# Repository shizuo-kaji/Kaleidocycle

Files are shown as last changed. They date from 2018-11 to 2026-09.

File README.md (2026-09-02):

[English](README.md) | [日本語](README.ja.md)

# Kaleidocycle: Geometry of Closed Linkages

Kaleidocycles are closed linkage mechanisms shaped like discrete Möbius bands.
Each unit consists of tetrahedral links that flip inside-out by rotating around
hinged joints, producing everting motions reminiscent of bubble rings. This
repository gathers asset needed to model, simulate, and fabricate these
mechanisms: Python tooling, Maple/Mathematica notebooks,
paper templates, and 3D-printable parts.

## Interactive demo

**[Open Kaleidocycle Studio](https://shizuo-kaji.github.io/Kaleidocycle/)**

The studio runs the animation by mKdV hierarchy and semi-discrete sine–Gordon flows,
and supports interactive editing of vertex positions and torsion-angles.

## Repository Tour
- [`python/`](python/) — Python scripts (package sources under
  `src/kaleidocycle/`, notebooks, examples)
- [`Kaleidocycle.mw`](Kaleidocycle.mw) / [`Kaleidocycle.nb`](Kaleidocycle.nb) —
  Maple and Mathematica scripts for symbolic construction, visualization, and
  template export
- [`3d_model/`](3d_model/) — STL for 3D printing
  (models by [Kamagata Design Studio](https://kdstudio.jp/))
- [`paper_model/`](paper_model/) — printable templates for hand-folded models
- [`hexagon/`](hexagon/) — hexaflexagon cousin plus a pictorial folding guide
  for kaleidocycles
- [`LICENSE`](LICENSE) — MIT license for the code (see the patent note below)

## Quick Start
### Python toolkit
1. `cd python`
2. `uv venv .venv && source .venv/bin/activate`
3. `pip install -e .[dev]`
4. `pytest` (or `pytest -k geometry`) to run the suite
5. `jupyter lab notebooks/FindKaleidocycles.ipynb` for interactive exploration

### Maple / Mathematica
Open `Kaleidocycle.mw` (Maple) or `Kaleidocycle.nb` (Mathematica) to reproduce
symbolic computations. Both scripts include visualization helpers
and export functions for paper templates and motion studies.

### Physical model assets
- Print STL files from `3d_model/` to fabricate kaleidocycles
- Use `paper_model/` templates for hand-folded prototypes; the `hexagon/` folder
  also contains instructions

## References & Further Reading
### Technical publications
- Shizuo Kaji, Kenji Kajiwara, Shota Shigetomi,
  [*An explicit construction of Kaleidocycles by elliptic theta functions*](https://doi.org/10.1111/sapm.70224),
  Studies in Applied Mathematics, 156, no. 5 (2026): e70224, [arXiv:2308.04977](https://arxiv.org/abs/2308.04977)
- Shizuo Kaji, Kenji Kajiwara, Hyeongki Park,
  [*Linkage Mechanisms Governed by Integrable Deformations of Discrete Space Curves*](https://arxiv.org/abs/1903.06360),
  in *Nonlinear Systems and Their Remarkable Mathematical Structures*, Vol. 2,
  CRC Press, 2019
- Shizuo Kaji,
  [*A closed linkage mechanism having the shape of a discrete Möbius strip*](https://arxiv.org/abs/1909.02885),
  JSPE Spring Meeting Symposium, 17 Mar 2018

<!-- ### Talks, slides, and abstracts
- (slides) [*Geometry of Kaleidocycles*](https://www.math.kyoto-u.ac.jp/~kaji/papers/Kaleidocycle21.pdf),
  Kyushu-Illinois Strategic Partnership Colloquia Series #2, 11 Mar 2021
- (slides, Japanese) [*Kaleidocycle*](https://www.math.kyoto-u.ac.jp/~kaji/papers/ShapeDesign.pdf),
  13 Mar 2021
- Shizuo Kaji, Eliot Fried, Michael Grunwald, Johannes Schoenke,
  [*Geometry of closed kinematic chain*](https://www.math.kyoto-u.ac.jp/~kaji/files/Kaleidocycle17.pdf),
  IMI Workshop on Mathematics in Interface, Dislocation and Structure of
  Crystals, 29 Aug 2017 -->

### Japanese-language articles
- プレスリリース:
  [現代数学と折紙から生まれた新しい機構「メビウス・カライドサイクル」](https://www.kyushu-u.ac.jp/ja/researches/view/908)
- プレスリリース:
  [任意個数の四面体に対してカライドサイクルの存在を数学的に証明](https://www.kyoto-u.ac.jp/ja/research-news/2026-05-19-3)
- 鍛冶静雄, [動く折り紙「カライドサイクル」をめぐる機構学と幾何学の出会い](https://www.math.kyoto-u.ac.jp/alumni/bulletin9/kaji.pdf), 京都大学数学教室同窓会誌, Vol 9, 2025
- 鍛冶静雄,
  [ユークリッド空間への図形の配置と設計への応用](https://drive.google.com/file/d/1T9TYKBqkQ1LdtojkK5dp09Pkyl5XI_wF/view?usp=sharing)
- 鍛冶静雄,
  [曲線の幾何学から生まれた閉リンク機構](https://drive.google.com/file/d/1CtwQHpcM_HEn3ooKfJ5y40s_B99IqRwR/view?usp=sharing),
  2018年度精密工学会春季大会 シンポジウム資料集, pp. 62–65
- 鍛冶静雄,
  [数理のクロスロード／かたちと動きの数理基盤／(1) リンク万華鏡](https://drive.google.com/file/d/1OzZajghUbhxeA3HFf4-TjSBeRZROcfiD/view?usp=sharing),
  数学セミナー 2019年6月号, 日本評論社
- 鍛冶静雄,
  [かたちを算する／おもちゃのかたち](https://www.nippyo.co.jp/shop/magazine/8418.html),
  数学セミナー 2021年1月号, 日本評論社

## Patent
The specific shape of the Möbius kaleidocycle is covered by the patent
* Shizuo Kaji, Johannes Schoenke, Eliot Fried, Michael Grunwald,
  [*Moebius Kaleidocycle*](https://patentscope2.wipo.int/search/en/detail.jsf?docId=WO2019167941),
  JP2018-033395 (Japan), 2019JP007314 (PCT), WO 2019167941, filed 27 Feb 2018.

However, feel free to use the material here for personal and educational projects.
For commercial use, contact the [Japan Science and Technology Agency](https://www.jst.go.jp/chizai/en/).

Some of the results described above are also published in
- Johannes Schoenke and Eliot Fried,
  [*Single degree of freedom everting ring linkages with nonorientable topology*](https://www.pnas.org/content/116/1/90.abstract),
  *PNAS* 116 (1), 90–95, 2019

## Gallery

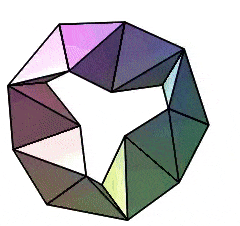
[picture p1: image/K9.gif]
K9

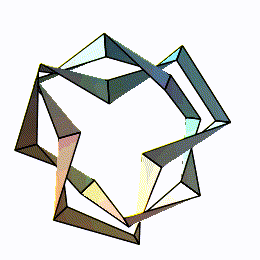
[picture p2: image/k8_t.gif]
K8

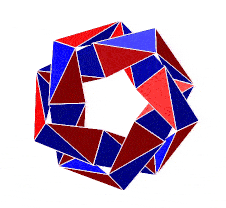
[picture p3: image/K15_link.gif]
K15

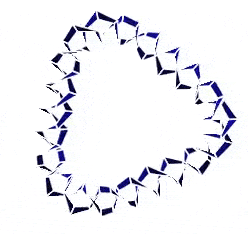
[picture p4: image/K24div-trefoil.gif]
K24div

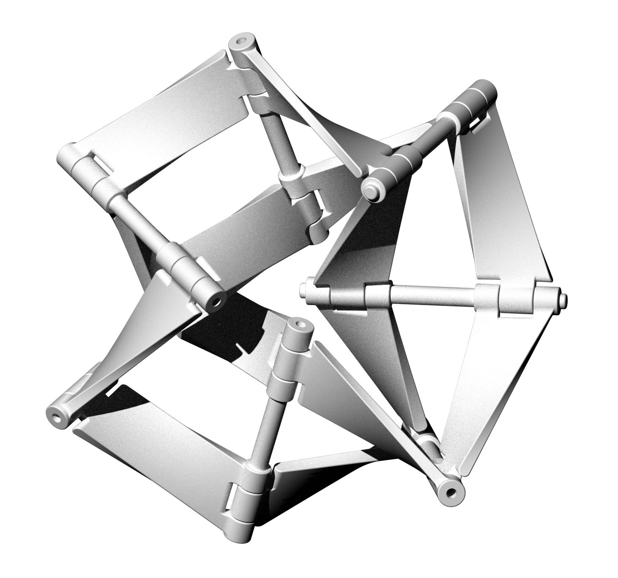
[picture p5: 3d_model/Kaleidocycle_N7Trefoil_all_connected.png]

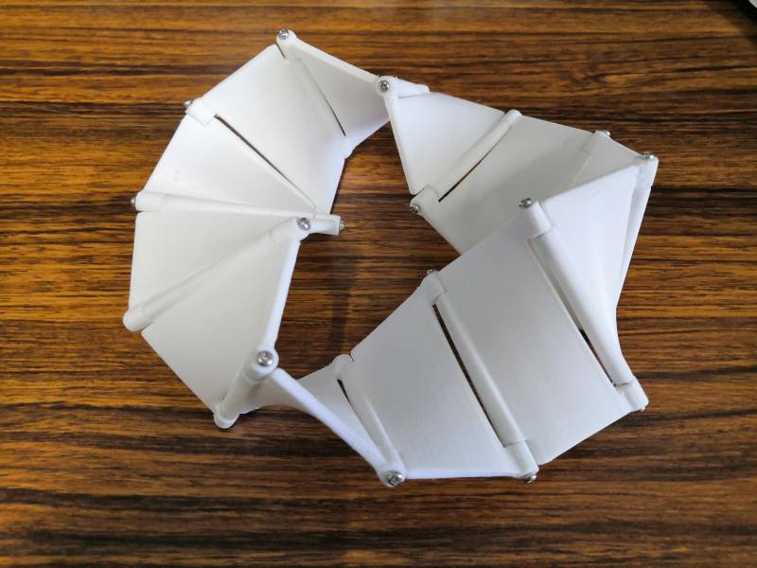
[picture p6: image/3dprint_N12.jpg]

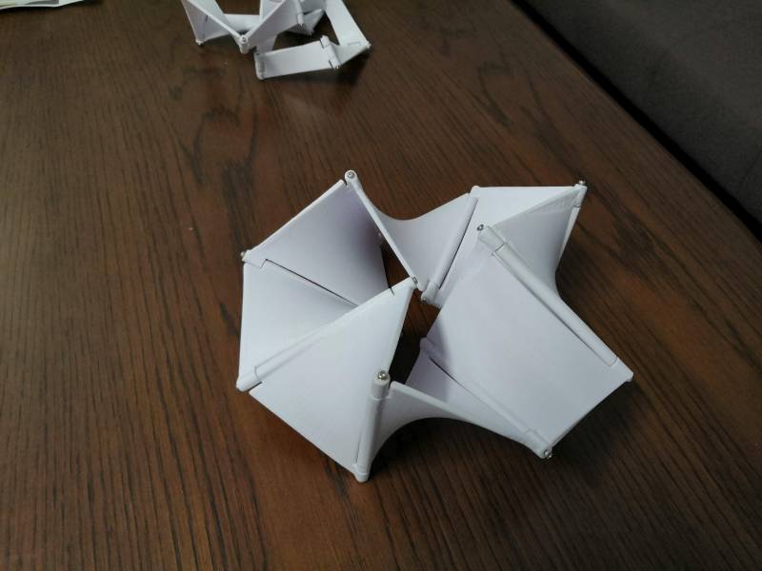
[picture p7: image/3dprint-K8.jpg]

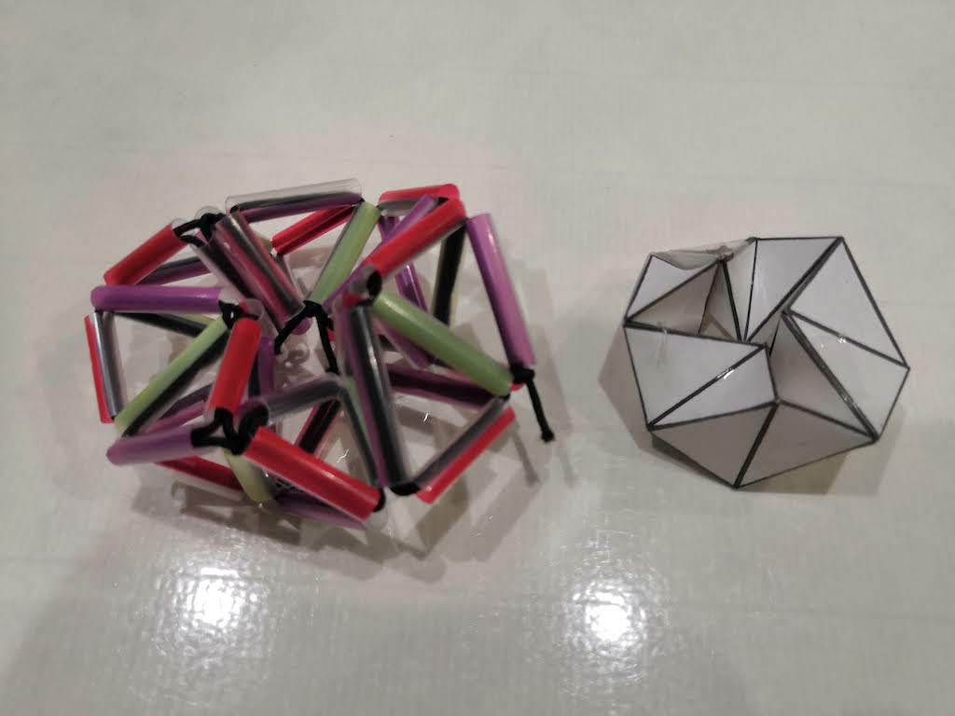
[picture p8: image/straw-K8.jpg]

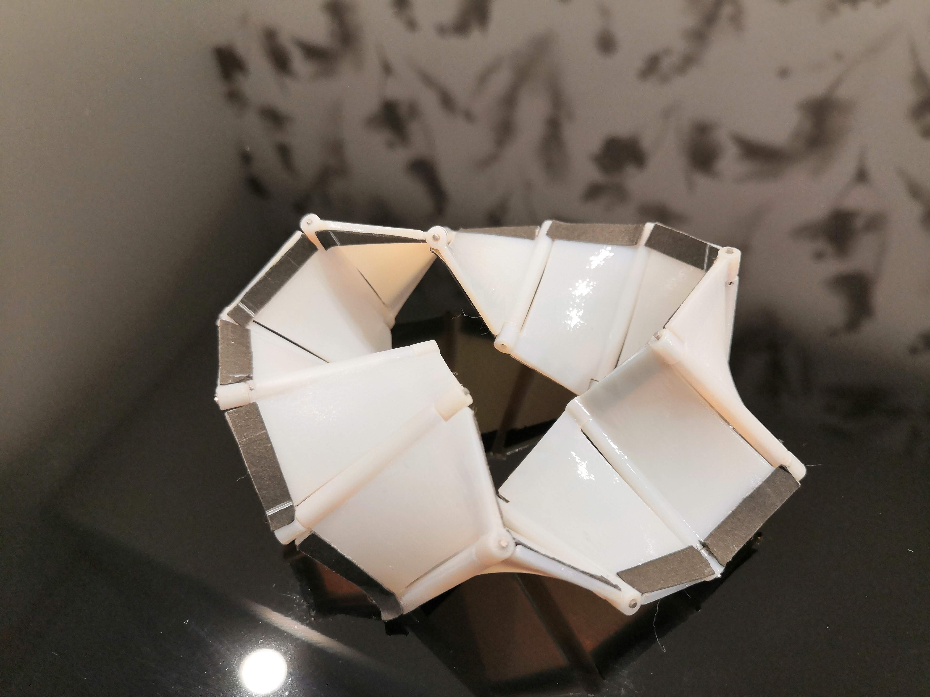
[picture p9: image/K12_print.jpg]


## License
All code and assets in this repository are released under the MIT License (see
[`LICENSE`](LICENSE)). Cite the references above when using or extending the
material in academic work.

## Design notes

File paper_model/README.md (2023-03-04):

[English](README.md) | [日本語](README.ja.md) 

# Paper model of Kaleidocycle

## Paper Plan

- [K7](paper-K7.pdf): Mobius Kaleidocycle with 7 tetrahedra
- [K8](paper-K8.pdf): Mobius Kaleidocycle with 8 tetrahedra
- [K9](paper-K9.pdf): Mobius Kaleidocycle with 9 tetrahedra
- Paper plans for Kaleidocycles with 10 or more tetrahedra can be obtained by [Maple code](../Kaleidocycle.mw)

## How to make

1. Cut along the outer boundary
2. The triangles in the right-most column and the bottom row are the glue allowance
3. Each row makes a tetrahedron
4. Crease every line firmly before folding tetrahedra
5. Horizontal lines should be creased in both mountain and valley and others in mountain
6. Apply some glue on the face of the gluing triangles
7. Fold tetrahedra from the top row
8. Insert the two gluing triangles at the bottom row into the tetrahedron corresponding to the first row

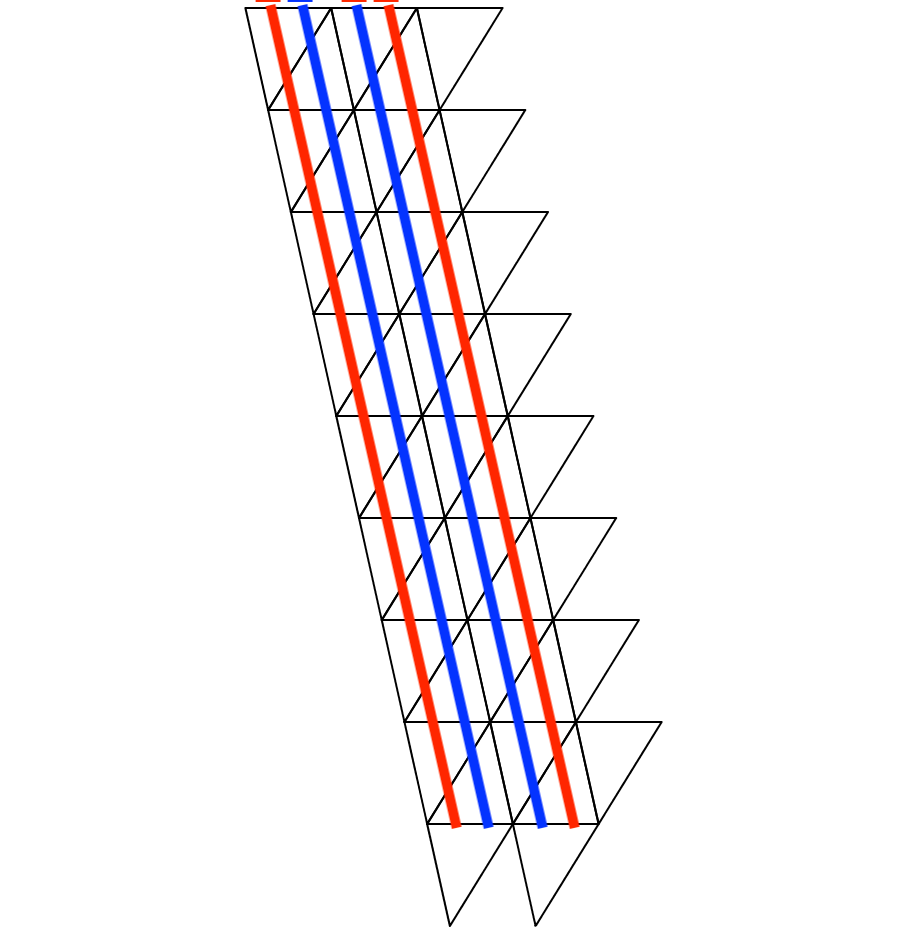
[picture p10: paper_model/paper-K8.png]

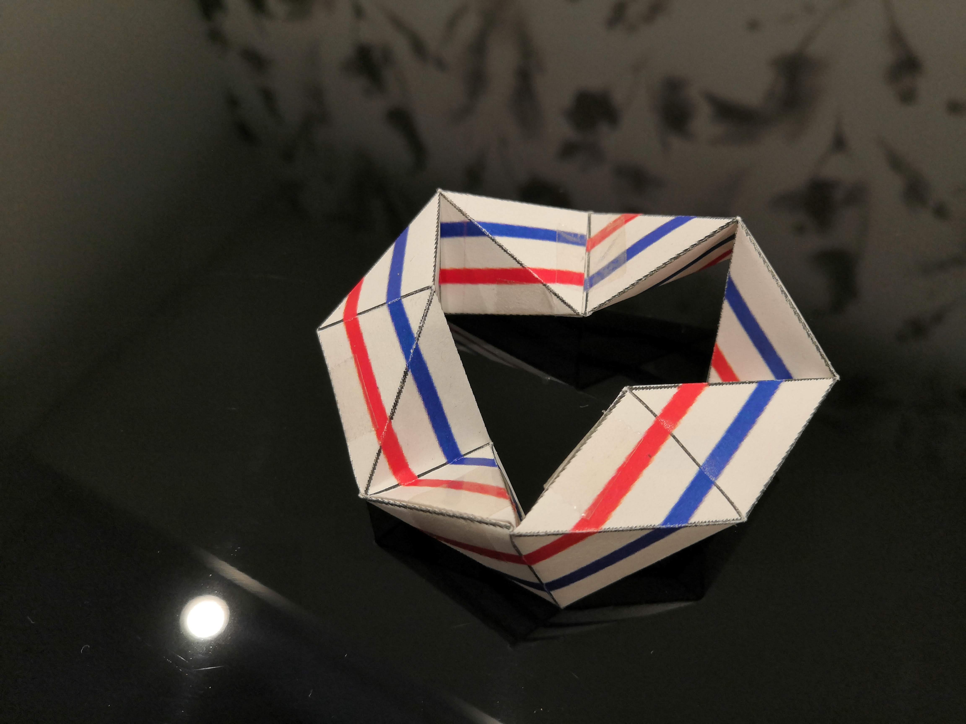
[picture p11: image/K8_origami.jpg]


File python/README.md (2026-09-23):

# Kaleidocycle Python Toolkit

This repository ports the Maple, Mathematica, and MATLAB kaleidocycle code into
a Python package. The package works with an N-kaleidocycle as `N + 1`
unit hinge vectors, also called binormals, in `R^3`. Adjacent hinges have
constant torsion, meaning their pairwise inner products are constant. Oriented
cycles end with the same hinge direction they started with; non-oriented cycles
end with the opposite direction.

The current Python package includes geometry, integrable curvature flows,
energies, constraints, solvers, theta-function constructions, animation tools,
reports, I/O, and plotting.

## Install

```bash
python -m pip install -e ".[dev]"
```

JAX is included in the development dependencies. For a smaller runtime install
with automatic differentiation support, use `python -m pip install -e ".[jax]"`.

Run the test suite with:

```bash
pytest
```

## Notebooks

Interactive examples live in `notebooks/`. Use `%matplotlib widget` for 3D
interaction and make sure the notebook kernel points at the project environment.

- `FindKaleidocycles.ipynb` explores optimization-based construction.
- `ExplicitConstructionWithTheta.ipynb` demonstrates analytic theta-function
  solutions.
- `Animation.ipynb` explores animation utilities.
- `IntegrableDeformations.ipynb` demonstrates the positive mKdV hierarchy,
  its spectral Hamiltonians and lifts, the anti-periodic sine--Gordon flow,
  and numerical conservation.
- `SelfCrossing.ipynb` certifies a K12 self-crossing under the first mKdV flow,
  with static diagnostics and an interactive 3D time slider.
- `KaleidocycleProperties.ipynb` inspects structural properties and residuals.
- `AnimationScalarProperties.ipynb` computes and plots animation diagnostics.
- `BackendComparison.ipynb` compares NumPy and optional JAX solver backends.
- `LocalDoF.ipynb` analyzes infinitesimal and finite degrees of freedom of the
  constraint-preserving motion at a given configuration.

## Interactive web studio

Select **Self-crossing K12 · first mKdV flow** in the studio's built-in menu
for the pre-contact counterexample (`counterexample_k12_self_crossing`). Its
certified decimal inputs are in `data/counterexamples/`, with the certificate
and interactive diagnostics in `notebooks/SelfCrossing.ipynb`. Rebuild the
shared sample and offline fallback with `python scripts/build_self_crossing.py`.

`web/` contains a three.js studio for the integrable hierarchy and constrained
editing of closed constant-torsion kaleidocycles. When it is served over HTTP,
the built-in menu reads the same canonical JSON files in
`data/kaleidocycles/` that notebooks load through `load_sample()`.

**[Open Kaleidocycle Studio](https://shizuo-kaji.github.io/Kaleidocycle/)**

```bash
python -m http.server 8000   # from this directory
```

then open <http://localhost:8000/web/>. Directly opening `web/index.html` also
works, using a generated static fallback because browsers do not permit a
`file://` page to fetch neighbouring JSON files. See `web/README.md` for details.

### Shared notebook/web samples

```python
from kaleidocycle import export_sample, load_sample

cycle = load_sample("generic_k15_noncritical")

# Promote a notebook result to the canonical built-in catalogue.
export_sample(
    cycle,
    "my_named_sample",
    metadata={"kind": "generic", "non_critical": True},
)
```

`export_json()` now writes a top-level `name` too; an explicit `name=...` wins,
then `Kaleidocycle.name`, and finally the output filename is used. After adding
or changing canonical samples, run `python scripts/build_web_samples.py` to
refresh `catalog.json` and the generated fallback used only in direct-file mode.

## Package Layout

- `src/kaleidocycle/geometry.py`: hinge frames, curves, curvature, torsion,
  writhe, twist, linking number, transformations between curves, tangents, and
  binormals, plus the `Kaleidocycle` class.
- `src/kaleidocycle/animation.py`: sine-Gordon flow, step/random animation
  generation, frame cleaning, alignment, sorting, curve conversion, and
  `KaleidocycleAnimation`.
- `src/kaleidocycle/integrable.py`: twisted curvature coordinates, discrete
  Frenet reconstruction, the positive mKdV hierarchy and compatible lifts,
  twisted-Floquet Hamiltonians, the anti-periodic sine--Gordon field, Poisson
  operator, variational recurrence, QRT invariant, and time integration.
- `src/kaleidocycle/theta.py`: Jacobi theta functions, closure equations,
  analytic curves, theta binormals, and theta animations.
- `src/kaleidocycle/constraints.py`: unit norm, closure, alignment, constant
  torsion, anchor, and curvature-recursion residuals.
- `src/kaleidocycle/energies.py`: bending, torsion, and dipole energies.
- `src/kaleidocycle/solvers.py`: optimization dispatch, Newton iteration,
  pseudoinverse utilities, multi-seed search, and curvature/torsion solvers.
- `src/kaleidocycle/optimality.py`: gradients, constraint Jacobians, tangent
  projection, and stationarity checks.
- `src/kaleidocycle/rigidity.py`: rigidity-matrix diagnostics, mechanism and
  self-stress bases, Calladine/Pellegrino counts, Connelly second-order stress
  tests, and finite-motion tracing wrappers.
- `src/kaleidocycle/visualization.py`: centreline, hinge, band, tetrahedron,
  paper-model, energy, and vertex-value plotting.
- `src/kaleidocycle/io.py`: JSON and CSV import/export.
- `src/kaleidocycle/samples.py`: shared named-sample catalogue, promotion, and
  presentable generic-sample selection.
- `src/kaleidocycle/report.py`: formatted diagnostic reports.

## Core Properties

`Kaleidocycle` and `KaleidocycleAnimation` expose the same high-level checks:

| Property | Meaning |
| --- | --- |
| `n` | Number of tetrahedra, equal to `len(hinges) - 1`. |
| `oriented` | Whether the first and last hinge directions agree. |
| `is_closed` | Whether the tangent closure residual is below tolerance. |
| `is_aligned` | Whether endpoint hinges satisfy the alignment rule. |
| `is_unit_norm` | Whether all hinge vectors have unit norm. |
| `constant_torsion` | Common torsion value, or `None` if not constant. |

The corresponding lower-level residuals are available from
`kaleidocycle.constraints`: `closure_residual`, `alignment_residuals`,
`unit_norm_residuals`, `constant_torsion_residuals`, `constraint_residuals`, and
`constraint_penalty`.

## Animation Diagnostics

`KaleidocycleAnimation.compute_scalar_property()` supports built-in scalar
properties:

| Name | Description |
| --- | --- |
| `bending_energy` or `bending` | Bobenko-Suris bending energy of the tangent vectors. |
| `mean_torsion` | Mean torsion angle across hinges. |
| `mean_curvature` | Mean discrete curvature across hinges. |
| `penalty` | Sum of squared constraint residuals. |
| `linking_number` | Topological linking number. |

Custom scalar properties can be added with a function:

```python
def max_curvature(hinges):
    from kaleidocycle.geometry import binormals_to_tangents, pairwise_curvature

    tangents = binormals_to_tangents(hinges, normalize=True)
    curvature = pairwise_curvature(hinges, tangents)
    return float(abs(curvature).max())

anim.compute_scalar_property("max_curvature", func=max_curvature)
```

## Analytic Theta Construction

`generate_theta_curve()` and `generate_theta_binormals()` implement the explicit
theta-function construction from `Kaleidocycle.m`. The binormal path follows the
Mathematica `Bx`, `By`, and `Bz` formulas. For parameters where the reference
formula has a removable near-singularity around `G = 0`, the implementation
automatically re-evaluates the same formula with higher precision instead of
falling back to curve-derived signs.

```python
from kaleidocycle import generate_theta_binormals

v = 0.07227972073349694
r = 0.30353311936556515
y = 0.9155431292909612
binormals = generate_theta_binormals(v, 0.0, r, y, N=38, t=0.0)
```

## Reports And Stationarity

Use `kc.report()` for a compact summary of geometric, topological, energetic,
and constraint diagnostics. Use `kc.is_stationary(energy, config=...)` to
project an energy gradient onto the constraint tangent space and estimate
whether a configuration is a constrained critical point.

```python
from kaleidocycle import Kaleidocycle
from kaleidocycle.constraints import ConstraintConfig

kc = Kaleidocycle(8, oriented=True, seed=42)
config = ConstraintConfig(oriented=True, constant_torsion=True)

print(kc.report())
print(kc.is_stationary("bending", tolerance=1e-4, config=config))
```

## Local Degrees Of Freedom

Several complementary routines analyze how many independent motions preserve
the constraints at a given configuration.

For the highest Jacobian accuracy, use the optional JAX backend in this
workflow whenever it is available:

```python
BACKEND = "jax"
```

`kc.local_dof()` performs a *linear* (infinitesimal) analysis: it returns the
dimension of `ker(J)`, where `J` is the constraint Jacobian. Global rigid
rotations `δh_i = ω × h_i` always lie in this nullspace, so they are
quotiented out by default (`subtract_rigid=True`). The returned dictionary
contains `dof`, `raw_dof`, `rigid_dof`, `rank`, singular values, and
optionally an orthonormal `basis` of shape `(n+1, 3, dof)`.

`rigidity_svd(hinges, config)` exposes the same Jacobian as a rigidity matrix
and returns explicit bases for infinitesimal mechanisms (`ker J`) and
self-stresses (`ker J.T`). `calladine_summary()` reports the
Pellegrino/Calladine identity
`mechanisms - self_stresses = variables - constraints`, with optional rigid
rotation subtraction. `connelly_second_order_test()` evaluates the
stress-weighted Hessian `d²(w·F)` on infinitesimal mechanisms for a
second-order obstruction check.

`kc.finite_motion_dof()` performs a *nonlinear* (finite-motion) analysis via
predictor-corrector continuation. It samples tangent directions from the
infinitesimal nullspace, takes finite predictor steps, projects back onto the
constraint manifold with Newton iteration, and reports the numerical rank of
the resulting displacement matrix. At a singular point of the constraint
variety, `finite_dof < infinitesimal_dof` because some tangents fail to
integrate to finite paths.

`kc.find_nearby_stationary(energy="mean_cos", config=...)` finds the nearest
critical point of an energy under the constraints by solving
`Π_{ker J} ∇E = 0` directly with `scipy.optimize.root`. Unlike gradient
descent it converges at saddle points — essential for analytically
constructed (e.g. theta-function) kaleidocycles that are saddles rather than
local minima.

`kc.follow_motion(config=..., direction_index=0)` runs a single bidirectional
predictor-corrector continuation along a chosen tangent direction and
returns the array of hinge frames.

`plot_vertex_trajectories(frames)` and `trajectory_dimensionality(curves)`
(in `kaleidocycle.visualization`) visualize and quantify the motion. The
helper `align_first_three(curve)` rigidly fixes the first three vertices to
kill the rigid-motion ambiguity.

For Kutzbach-Grübler-style DoF counting (`dof = N − 6` generically) use
`ConstraintConfig(full_alignment=True, reference_torsion=h_0·h_1)` — the
default scalar alignment has rank-0 contribution at the manifold.

```python
from kaleidocycle import (
    Kaleidocycle,
    ConstraintConfig,
    calladine_summary,
    connelly_second_order_test,
    rigidity_svd,
    trace_finite_motion,
)

kc = Kaleidocycle(8, oriented=True, seed=42)
BACKEND = "jax"

# Kutzbach-Grübler "physical" constraint set
cfg = ConstraintConfig(
    oriented=True, constant_torsion=True, full_alignment=True,
    reference_torsion=float(kc.hinges[0] @ kc.hinges[1]),
)

rig = rigidity_svd(kc.hinges, cfg, tol=1e-8, backend=BACKEND)
summary = calladine_summary(kc.hinges, cfg, tol=1e-8, backend=BACKEND)

lin = kc.local_dof(config=cfg, tol=1e-6, backend=BACKEND)
print(f"infinitesimal DoF: {lin['dof']}")
print(f"self stresses:     {summary.self_stresses}")

if rig.self_stress_count:
    second = connelly_second_order_test(
        kc.hinges, cfg, stress_index=0, backend=BACKEND
    )
    print(second.eigenvalues)

fin = kc.finite_motion_dof(
    config=cfg, seed=0, step_size=1e-3, n_steps=15, backend=BACKEND
)
print(f"finite DoF:        {fin['finite_dof']}")

frames = trace_finite_motion(
    kc.hinges, cfg, direction_index=0, step_size=5e-4,
    n_steps=80, backend=BACKEND,
)
```

See `notebooks/LocalDoF.ipynb` for a complete worked example covering the
K-G count, rigidity matrix rank, Calladine/Pellegrino self-stress diagnostics,
Connelly second-order checks, Möbius / theta-construction stationary detection,
and the 1-DoF vertex-trajectory visualization. The notebook uses the JAX backend
for Jacobian-based calculations wherever the current APIs support it.

## Integrable deformation

```python
import numpy as np

from kaleidocycle import (
    framed_polygon_from_binormals,
    import_json,
    integrate_curvature_flow,
)

kc = import_json("notebooks/output/kaleidocycle_k10_nonoriented_bending.json")
initial = framed_polygon_from_binormals(kc.hinges)
evolution = integrate_curvature_flow(
    initial.curvatures,
    initial.torsion_angle,
    np.linspace(0.0, 1.0, 101),
    flow="sine-gordon",
    sign=initial.sign,
    initial_frame=initial.frames[0],
)

configurations = evolution.configurations()
print(np.ptp(evolution.first_hamiltonian))
print(np.linalg.norm(configurations[-1].closure_residual))
```

The integrable API uses the Cayley curvature
`kappa = 2*tan(phi/2)`. `sign=1` means periodic/oriented binormals and
`sign=-1` means anti-periodic/anti-oriented binormals. Every positive mKdV flow
is available through `flow="mkdvN"` (or `flow=N`) for both signs; the
sine--Gordon flow is defined only for `sign=-1`.

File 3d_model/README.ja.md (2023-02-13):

[English](README.md) | [日本語](README.ja.md) 

# 3Dプリンタ用のモデル

## ファイル

以下の種類の STL ファイルがあります．

- K8: 8個のパネルからなるメビウス・カライドサイクル
[K8パネル](Kaleidocycle_N8_band.stl), [K8ヒンジ](Kaleidocycle_N8_hinge.stl),  [K8完成形](Kaleidocycle_N8_all.stl)
- K12: 12個のパネルからなるメビウス・カライドサイクル．
[K12パネル](Kaleidocycle_N12_band.stl), [K12ヒンジ](Kaleidocycle_N12_hinge_TRUSCO_B05-0215.stl), [K12完成形](Kaleidocycle_N12_all.stl)
- K7Trefoil: 14個の四面体からなるカライドサイクル．一次元自由度で回すためには，２枚ずつのパネルを長いヒンジで連結する必要があります．
[K7Treパネル](Kaleidocycle_N7Trefoil_band.stl), [K7Treヒンジ](Kaleidocycle_N7Trefoil_hinge.stl), [K7Tre完成形](Kaleidocycle_N7Trefoil_all_connected.stl)

## 作り方

パネル・ヒンジをそれぞれ適切な数だけ STL ファイルから印刷して，組み上げてください．

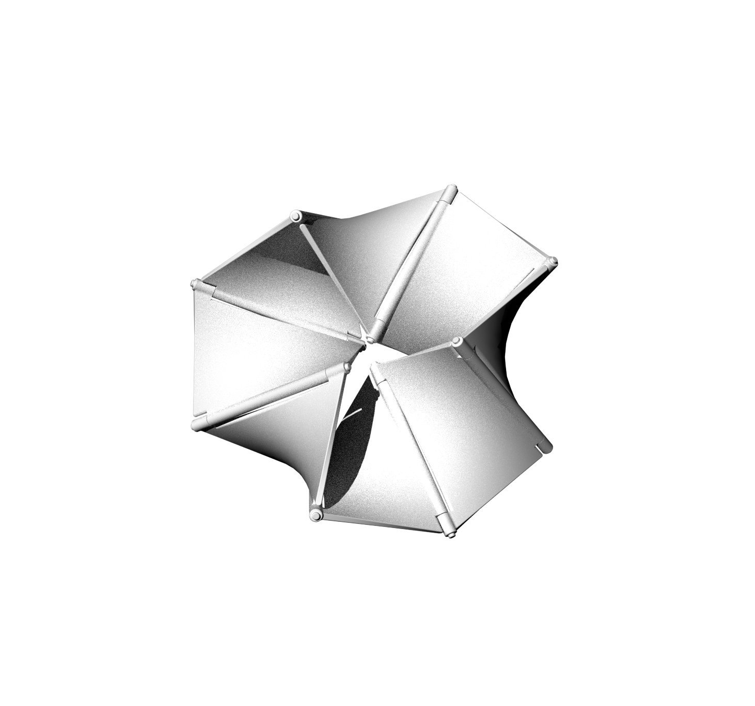
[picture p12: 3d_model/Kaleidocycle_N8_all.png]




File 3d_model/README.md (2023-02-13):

[English](README.md) | [日本語](README.ja.md) 

# 3D printable model of Kaleidocycle

## Model files

STL files for the followings are avaiable.

- K8: with 8 panels. 
[K8 panel](Kaleidocycle_N8_band.stl), [K8 hinge](Kaleidocycle_N8_hinge.stl), [K8 assembled](Kaleidocycle_N8_all.stl)
- N12: with 12 panels.
[K12 panel](Kaleidocycle_N12_band.stl), [K12 hinge](Kaleidocycle_N12_hinge_TRUSCO_B05-0215.stl), [K12 assembled](Kaleidocycle_N12_all.stl)
- N7 Trefoil: with 14 panels forming a trefoil knot (doubley-covered K7). 
For this to have 1-DoF, pairs of panels should be connected together with long hinges. 
[K7Tre panel](Kaleidocycle_N7Trefoil_band.stl), [K7Tre hinge](Kaleidocycle_N7Trefoil_hinge.stl), [K7Tre assembled](Kaleidocycle_N7Trefoil_all_connected.stl)

## How to make

Print the appropriate numbers of the parts (band and hinge) from the corresponding STL files.





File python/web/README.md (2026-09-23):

# Kaleidocycle Studio

**[Open the hosted studio](https://shizuo-kaji.github.io/Kaleidocycle/)**

Kaleidocycle Studio is a local, interactive laboratory for closed,
constant-torsion kaleidocycles. It reconstructs the ring from Cayley curvature
coordinates, evolves it with the integrable hierarchy and keeps direct edits on
the closed-configuration locus.

The interface uses British English throughout.

## Run it without a server

Open [`index.html`](index.html) directly in a modern browser. A `file://` URL is
fully supported; no HTTP server, package installation or network connection is
required.

This is possible because:

- three.js is vendored in `vendor/` rather than imported from a CDN;
- the application uses ordinary local scripts rather than ES modules;
- the generated `sample-fallback.js` mirrors the canonical JSON catalogue; and
- arbitrary JSON files are read with `FileReader`, by file picker or drop.

Serving the repository root over HTTP is recommended while developing: in that
mode the studio reads each built-in directly from `data/kaleidocycles/`.

## Integrable motion

The state variable is the Cayley curvature

```text
kappa[n] = 2 tan(phi[n] / 2),
```

with the twisted boundary condition `x[n + N] = sign x[n]`. The application
implements the same positive semi-discrete mKdV hierarchy as
`src/kaleidocycle/integrable.py`:

- `X(1)` and `X(2)` use the explicit local formulae;
- every higher `X(j)` is generated from the exact gradient of the logarithmic
  twisted-Floquet Hamiltonian and the common Poisson operator; and
- the order control runs from 1 through the finite Cayley–Hamilton bound `N`.

The semi-discrete sine–Gordon flow is also available for anti-oriented cycles.
Time integration uses RK4. The time step is automatically reduced when a high
hierarchy field is large, and a small periodic constraint correction controls
floating-point drift. The displayed `t` is the actual integrated flow time.

The Diagnostics panel updates **Wr** (standard Gauss writhe) and
**Lk = Wr + Nμ/(2π)** with each flow step or edit. Anti-oriented cycles can have
half-integer Lk. Both values display `—` at a detected self-contact or when the
closure error exceeds `1e-6`; the normalisation matches `SelfCrossing.ipynb`.

## Interactive initial geometry

The geometry editor operates on curvature coordinates rather than moving mesh
vertices independently.

### Pulling a vertex

Select a white centre-line handle and drag it in the screen-facing plane. At
each update the editor:

1. differentiates closure and monodromy with respect to all curvatures;
2. constructs the tangent-space projector of those six constraints;
3. solves for the closest motion of the selected vertex within that tangent
   space; and
4. projects the result back onto exact closure and monodromy.

The selected point follows the pointer only as far as the local configuration
space permits. The rest of the ring moves coherently and constant torsion is
preserved by reconstruction.

### Changing torsion

The torsion-angle slider changes `mu` by continuation. Each small change in
`mu` is followed by a least-norm curvature correction. If the requested value
leaves the current local branch, the previous valid configuration is restored
and the interface reports that the limit was reached.

After editing, **Use as initial** makes the current shape the reset state.
**Export JSON** writes the constrained configuration in the package's usual
`hinges`, `tangents` and `curve` format.

## Built-in data

The repository-level `data/kaleidocycles/` directory is the single source of
truth. It contains the K7–K9 reference configurations and three generic samples,
including the non-critical, anti-oriented K15 used in
`IntegrableDeformations.ipynb`. The generic configurations were selected from
many feasible seeds using separation, spatial extent and three-dimensionality,
so they read as open rings instead of collapsed tangles. K15 is the default
because it exposes a five-dimensional span of independent hierarchy motions.

With a server running from the repository root, the browser loads
`data/kaleidocycles/catalog.json` and its JSON entries directly. Direct-file
mode cannot fetch neighbouring JSON under browser security rules, so it uses
`sample-fallback.js`, a generated mirror of exactly the same files.

Notebook code can load or promote a shared sample with:

```python
from kaleidocycle import export_sample, load_sample

cycle = load_sample("generic_k15_noncritical")
export_sample(cycle, "my_named_sample", metadata={"kind": "generic"})
```

After adding or changing a canonical file, rebuild the catalogue and direct-file
fallback:

```bash
python scripts/build_web_samples.py
```

## Files

- `index.html` — British-English interface and responsive styling.
- `viewer.js` — three.js rendering, camera gestures, picking and UI wiring.
- `sim.js` — server-independent curvature model, constraints and flows; it can
  also be loaded by Node for mathematical tests.
- `sample-fallback.js` — generated direct-file fallback; do not edit by hand.
- `../scripts/build_web_samples.py` — catalogue/fallback generator.
- `../data/kaleidocycles/` — canonical named JSON configurations and catalogue.
- `vendor/` — local three.js build and licence.

The web editor deliberately replaces the old Rapier rigid-body simulation.
That simulation approximated hinge constraints dynamically; the new editor is
instead designed around the closed constant-torsion locus and the integrable
flows studied in the paper.

## Self-crossing counterexample

Select **Self-crossing K12 · first mKdV flow** in the studio's built-in menu.
This loads `counterexample_k12_self_crossing`, an embedded pre-contact
configuration at `t = -0.002` on the certified K12 first-flow orbit. Evolve it
with `X(1)` to explore the crossing.

`notebooks/SelfCrossing.ipynb` executes the interval certificate and provides
static diagnostics and an interactive view. Rebuild the shared sample and
studio's offline fallback with `python scripts/build_self_crossing.py` from
`data/counterexamples/mkdv_self_crossing_k12.json`.

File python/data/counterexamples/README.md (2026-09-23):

# A transverse self-crossing of the first mKdV flow

`mkdv_self_crossing_k12.json` specifies an anti-oriented K12 with torsion angle
`mu = 6/5`. Edge indices are zero-based. Edges 0 and 6 meet at time zero.
All decimal strings in `center` and `inverse_jacobian` are exact certificate
inputs; they must not be rounded or converted through binary floats before
interval evaluation.

The 14 centre coordinates are `(phi_0, ..., phi_11, u, v)`. The five angles
at indices `[3, 5, 6, 7, 9]` are held fixed. The other seven angles and the
interior edge fractions `u, v` vary in an infinity-norm box of radius `1e-20`.
Reconstruct with `F_0 = I`, `gamma_0 = 0` and
`F_(n+1) = F_n R1(mu) R3(phi_(n+1))`, using `phi_12 = -phi_0`.

The nine equations are position closure, the three skew components of
`F_12 diag(1,-1,-1)`, and
`gamma_0 + u T_0 - gamma_6 - v T_6 = 0`.
The checker also verifies that the frame trace is greater than 2.9, excluding
the half-turn solutions of the skew equations.

The stored matrix B approximates the inverse Jacobian. Outward-rounded
70-digit interval arithmetic, with automatic derivatives over the full box,
verifies `||B f(center)||_inf < 1e-58` and
`sup ||I - B Df||_inf < 1e-15`. The Newton map is a contraction from the box
into itself, giving a unique exact contact. No root-finder output is trusted
without these checks.

At the contact, all joints are regular and all 53 other non-adjacent edge
pairs have distance greater than 0.0129. For the first-flow vertex velocities
`V_n = F_n (cos(mu), -z_n cos(mu), -z_n sin(mu))`, the relative velocity
`W = (1-u)V_0 + uV_1 - (1-v)V_6 - vV_7` satisfies
`-3.283 < dot(cross(T_0,T_6), W) < -3.281`.
The contact equation has an invertible Jacobian in `(time,u,v)`. It follows
that the crossing is isolated and the nearby trajectories on either side
are embedded. Choosing a nearby negative time as the initial time disproves
unconditional embeddedness preservation.

Run from `python/`, using the project Python environment:

```bash
python -c 'from kaleidocycle.collision_certificate import certify_crossing; print(certify_crossing())'
python scripts/build_self_crossing.py
pytest tests/test_collisions.py
```

`notebooks/SelfCrossing.ipynb` executes the certificate and displays static and
interactive views. In the studio's built-in menu, select **Self-crossing K12 ·
first mKdV flow** (`counterexample_k12_self_crossing`) for the numerical
pre-contact configuration. The exact input is this certificate,
not the rounded geometry in the visualisation assets.

Trajectory samples use DOP853 without constraint projection. Their plotting
interval is `[-0.002, 0.002]`; the interval proof concerns the exact local
crossing, not every time-integration sample. Standard Gauss writhe jumps by
-2, with `Tw = 12*1.2/(2*pi)`. The half-integral self-linking number
`Lk = Tw + Wr` changes from 4.5 to 2.5; the integer twisting number is
`T = 2 Lk`. Wr and Lk are not evaluated at the contact. This normalisation
is distinct from the legacy `geometry.writhe` API.

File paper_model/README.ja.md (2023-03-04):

[English](README.md) | [日本語](README.ja.md) 

# カライドサイクルの折り方

## 展開図

- [K7](paper-K7.pdf): 7個の四面体からなるメビウス・カライドサイクル
- [K8](paper-K8.pdf): 8個の四面体からなるメビウス・カライドサイクル
- [K9](paper-K9.pdf): 9個の四面体からなるメビウス・カライドサイクル
- 10個以上の展開図は [Mapleプログラム](../Kaleidocycle.mw) で生成できます(Maple というソフトウェアが必要です)

## 折り方

1. 外側の線に沿って展開図を切り出します．
2. 右端の列と最下段の三角形はのりしろです
3. 横一段，のりしろを含めて５つの三角形が一つの四面体になります．
4. 折り始める前に，すべての折り線によく折り目を付けてください．
5. 水平な折り線は山折り谷折り両方，それ以外は山折りの折り目を付けてください．
6. のりしろの三角形にのりをつけてください．
7. 上の段から順に四面体に折ってゆきます．
8. 最後に最下段の２枚ののりしろ三角形を，最上段の四面体に差し込んで完成です．




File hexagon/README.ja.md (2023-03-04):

[English](README.md) | [日本語](README.ja.md) 

# ヘクサフレクサゴンの折り方

カライドサイクルの親戚として，ヘクサフレクサゴンというやはりクルクルと回して色々な面が出せる折り紙があります．
ここには世界地図が印刷され，回すたびに世界各地が現れるヘクサフレクサゴンの展開図があります．
Schwarz-Christoffel写像というものを利用して，各地域が角度を保って(等角に)六角形の面に写されています．
このモデルは Lai Hsin-Yu さんと Kai-Hsiang Wang さんにより [NCTS Undergraduate Summer Research Program 2018](https://ncts.ntu.edu.tw/news_detail.php?nid=59)においてデザインされました.

## ファイル

- [Paper model](worldmap_hexagon_all.pdf): ヘクサフレクサゴンの折り紙展開図
- [Long instruction](instruction_hexaflexa_long.pdf): ヘクサフレクサゴンとカライドサイクルの折り方の説明．
- [Short instruction](instruction_short.pdf): 上記の簡易版．

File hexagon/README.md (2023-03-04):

[English](README.md) | [日本語](README.ja.md) 

# Paper model of Hexaflexagon

Hexaflexagon is a two-dimensional cousin of Kaleidocycle that turns to reveal different faces.
This directory contains a paper model of a hexaflexagon with a world-map printed on it.
Each portion of the world is mapped to a hexagon by preserving angles (that is, conformally) using the Schwarz-Christoffel mapping.
It is designed by Lai Hsin-Yu and Kai-Hsiang Wang during [NCTS Undergraduate Summer Research Program 2018](https://ncts.ntu.edu.tw/news_detail.php?nid=59).

## Paper Plan

- [Paper model](worldmap_hexagon_all.pdf): Hexaflexagon with a conformally-printed world map.
- [Long instruction](instruction_hexaflexa_long.pdf): (in Japanese) A detailed instruction on how to fold.
- [Short instruction](instruction_short.pdf): (in Japanese) A short version of above.



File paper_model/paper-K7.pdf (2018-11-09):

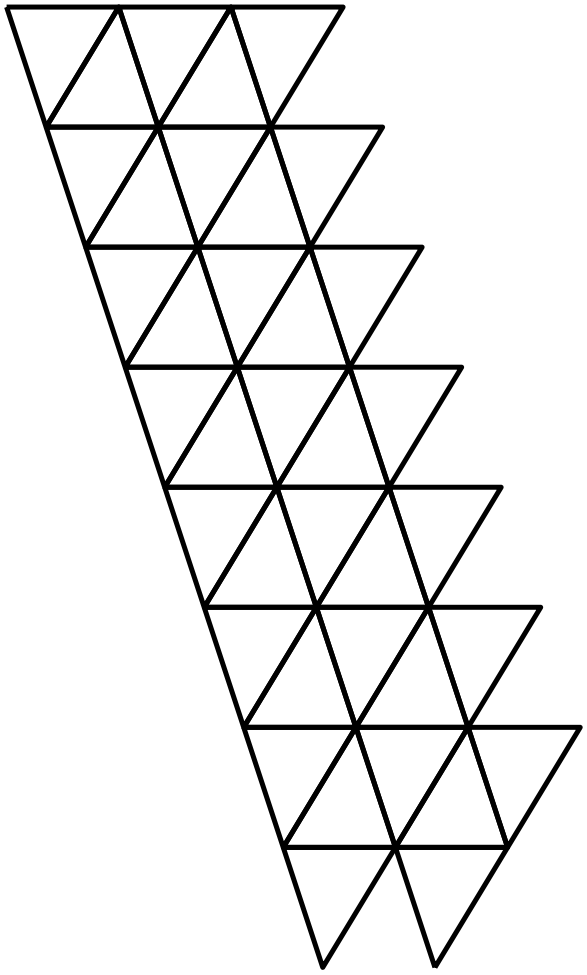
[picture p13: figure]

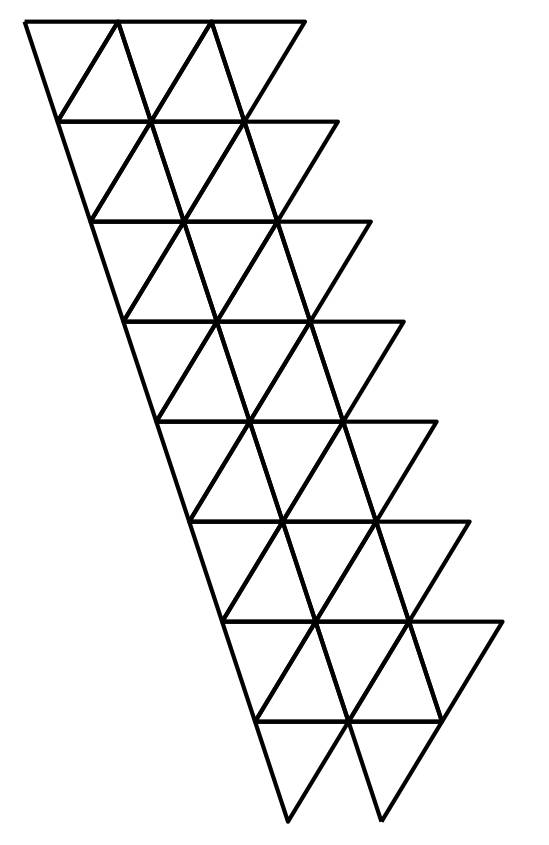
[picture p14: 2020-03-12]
paper_model/paper-K7.jpg

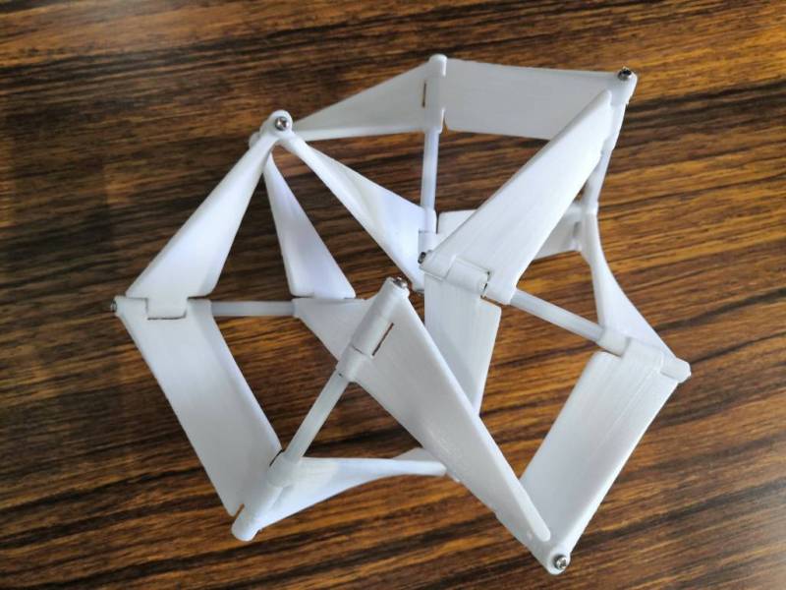
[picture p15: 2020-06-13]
image/3dprint_N7_trefoil.jpg

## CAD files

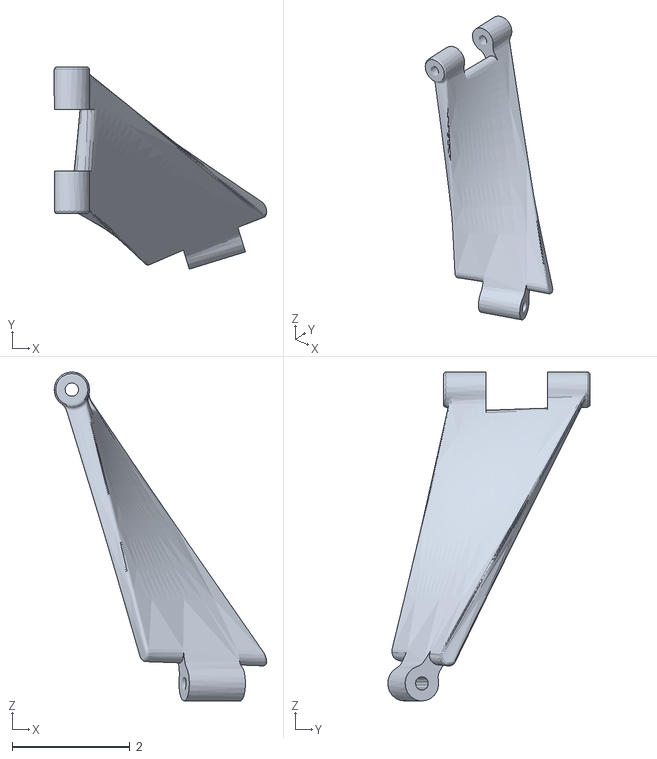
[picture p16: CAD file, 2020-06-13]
3d_model/Kaleidocycle_N7Trefoil_band_chiral.stl
3.62 x 3.44 x 5.60

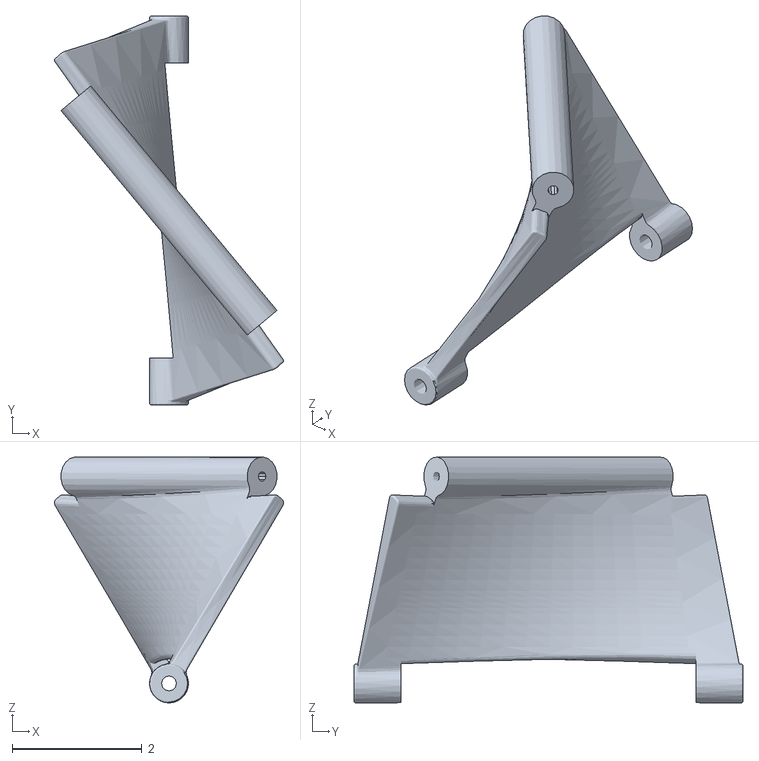
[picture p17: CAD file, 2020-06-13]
3d_model/Kaleidocycle_N12_band.stl
3.54 x 6.00 x 3.79

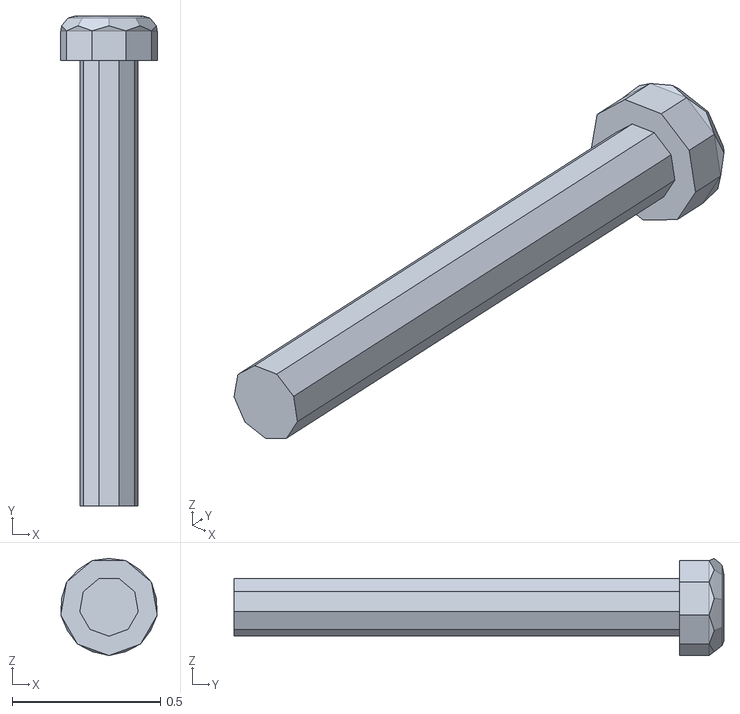
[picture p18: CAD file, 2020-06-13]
3d_model/Kaleidocycle_N12_hinge_TRUSCO_B05-0215.stl
0.325 x 1.65 x 0.327

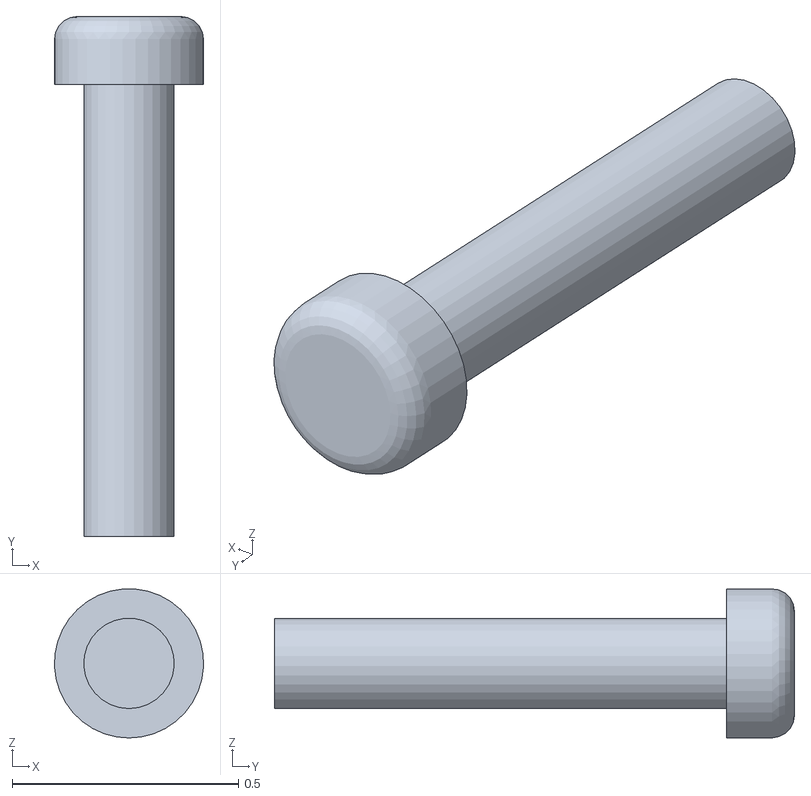
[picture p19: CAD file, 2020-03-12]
3d_model/Kaleidocycle_N7Trefoil_hinge.stl
0.33 x 1.15 x 0.329

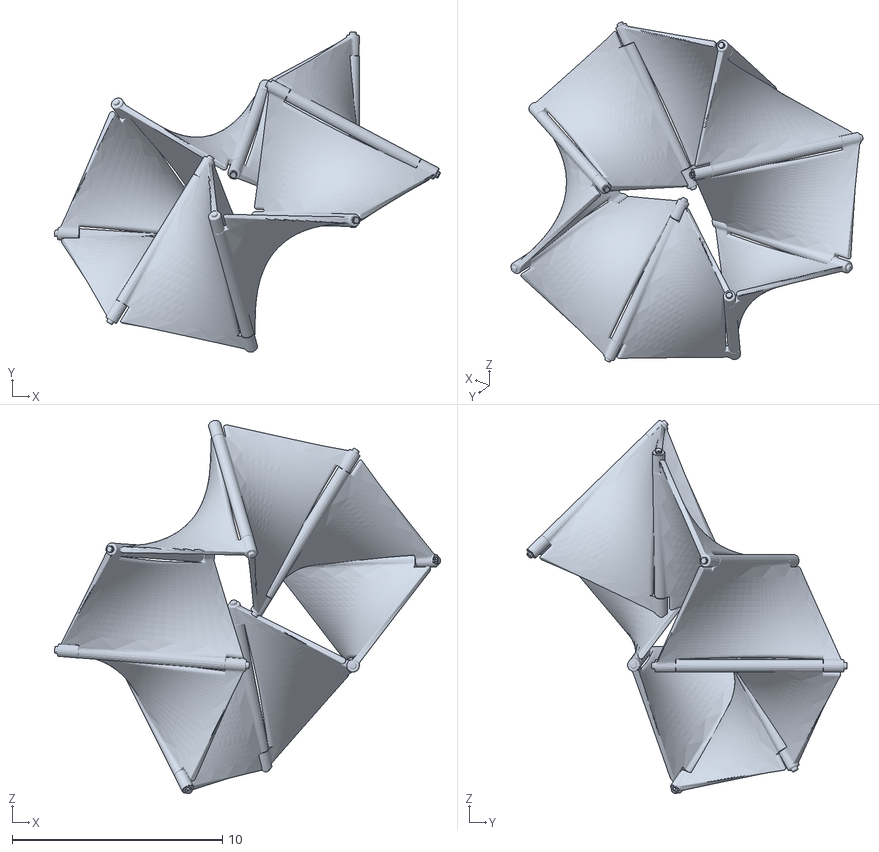
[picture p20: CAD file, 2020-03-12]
3d_model/Kaleidocycle_N8_all.stl
18.4 x 15.2 x 17.8

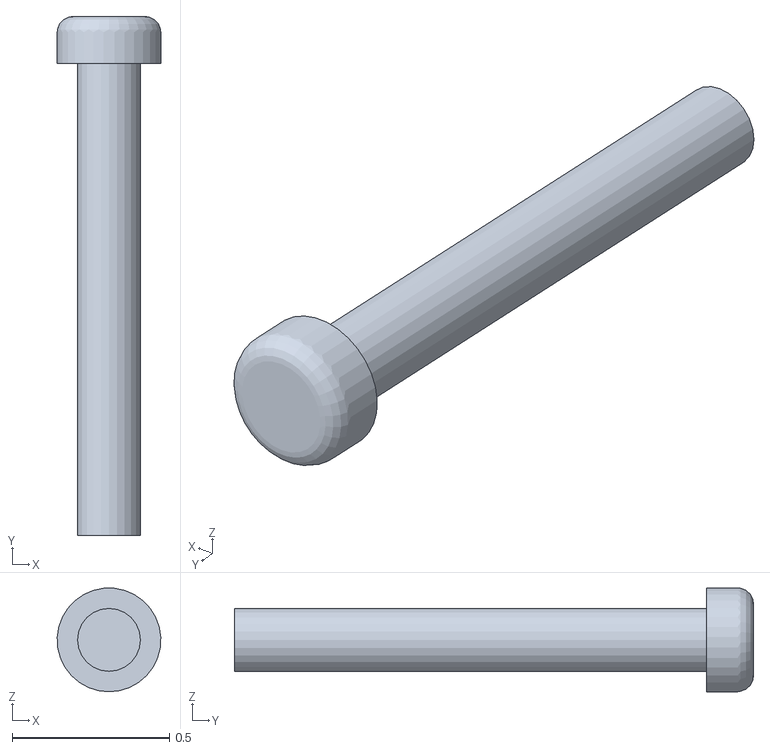
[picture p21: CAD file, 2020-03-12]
3d_model/Kaleidocycle_N8_hinge.stl
0.33 x 1.65 x 0.329

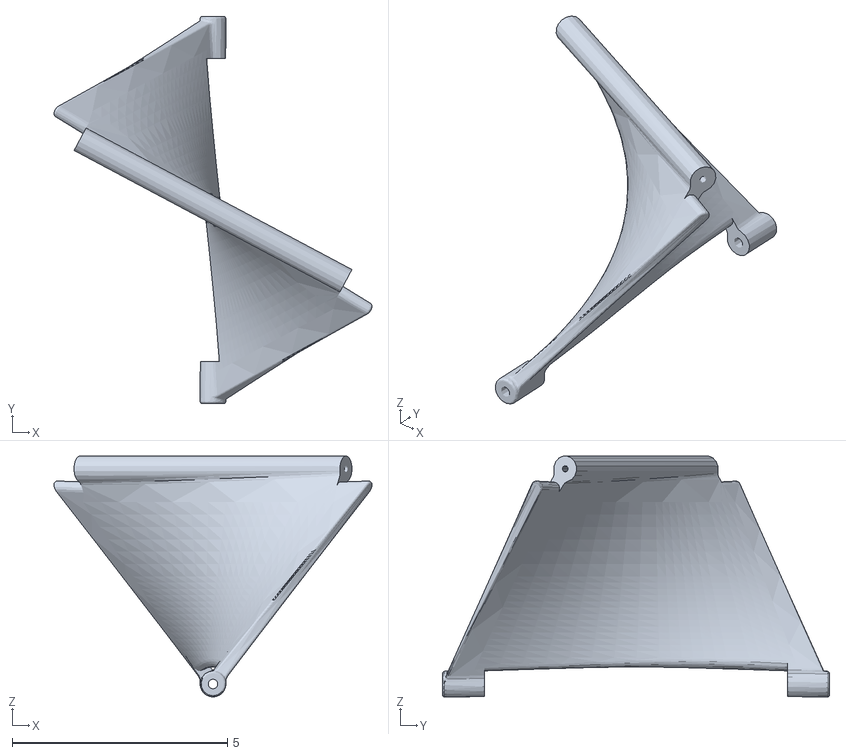
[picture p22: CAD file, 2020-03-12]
3d_model/Kaleidocycle_N8_band.stl
7.39 x 9.00 x 5.59

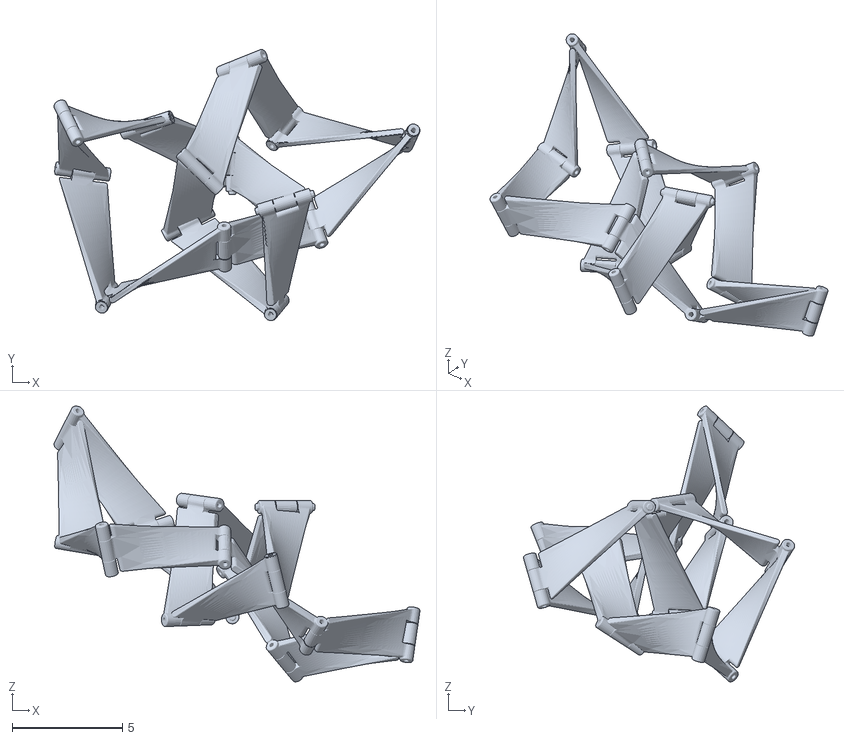
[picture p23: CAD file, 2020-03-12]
3d_model/Kaleidocycle_N7Trefoil_all.stl
16.6 x 12.3 x 12.5

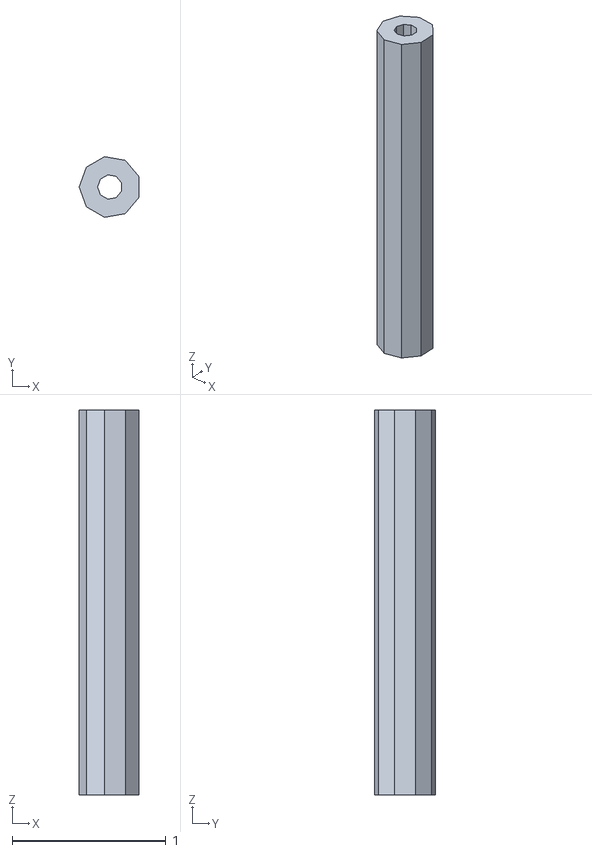
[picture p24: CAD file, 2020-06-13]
3d_model/MISUMI_SB-J2-25.stl
0.388 x 0.394 x 2.50

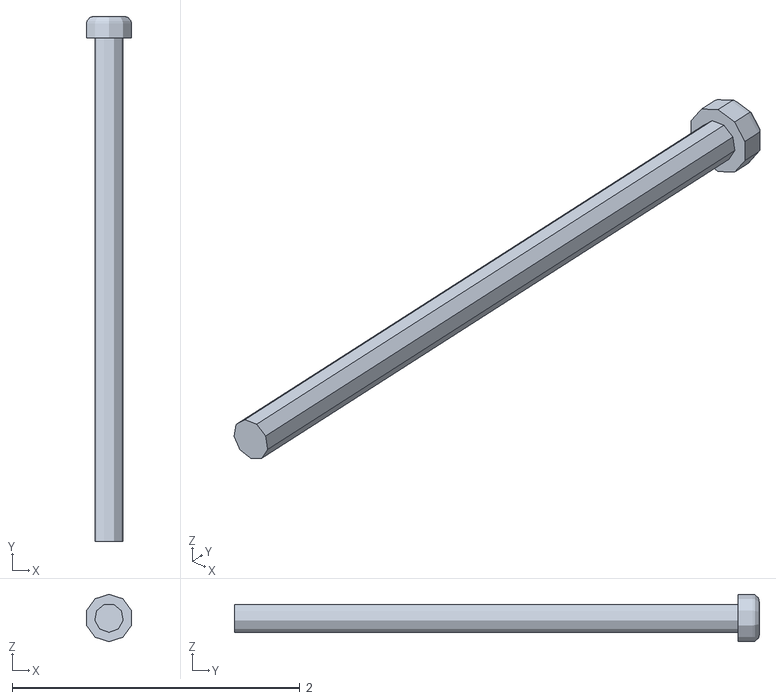
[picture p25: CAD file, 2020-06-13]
3d_model/MISUMI_CSPPN-SUS-M2-35.stl
0.314 x 3.65 x 0.33

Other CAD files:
3d_model/Kaleidocycle_N7Trefoil_band.stl

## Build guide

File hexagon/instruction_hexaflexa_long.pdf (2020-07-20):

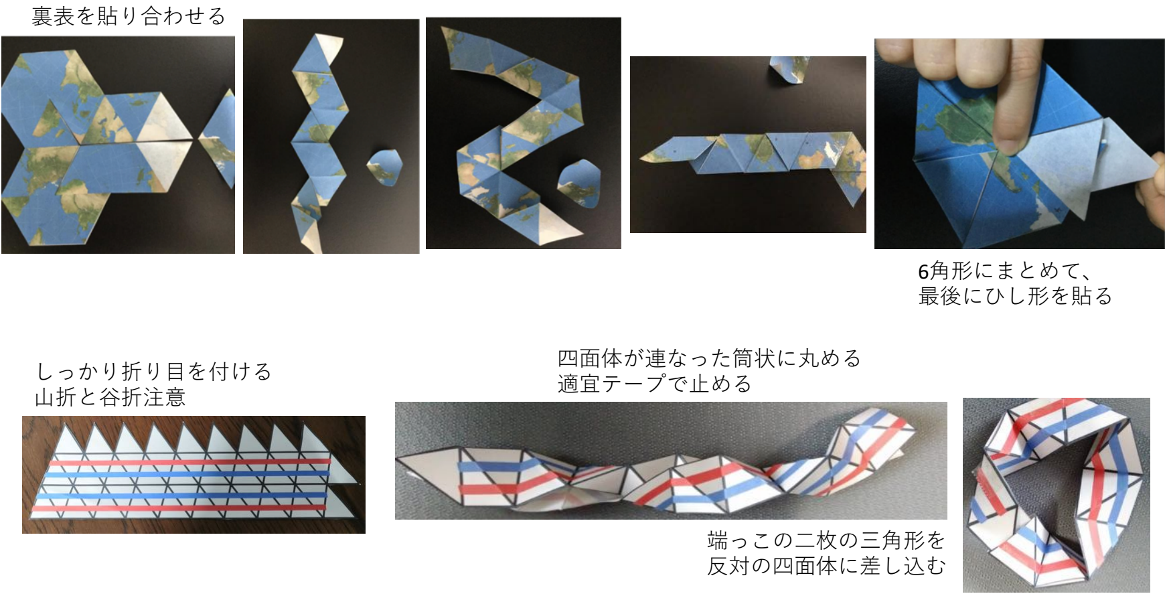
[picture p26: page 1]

6⾓形にまとめて、
最後にひし形を貼る

裏表を貼り合わせる

端っこの⼆枚の三⾓形を
反対の四⾯体に差し込む

四⾯体が連なった筒状に丸める
適宜テープで⽌める しっかり折り⽬を付ける
⼭折と⾕折注意

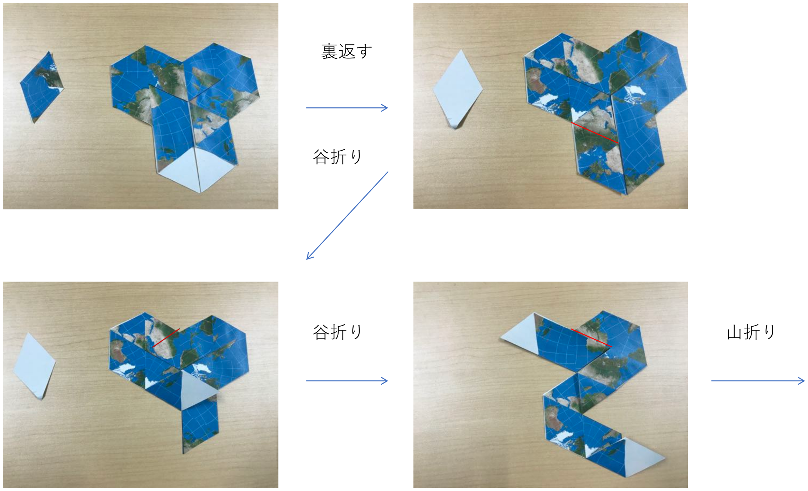
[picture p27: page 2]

裏返す

⾕折り

⾕折り | ⼭折り

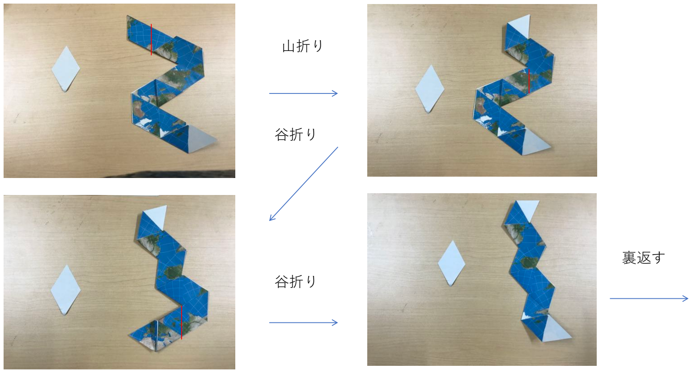
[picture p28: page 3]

⼭折り

⾕折り

⾕折り

裏返す

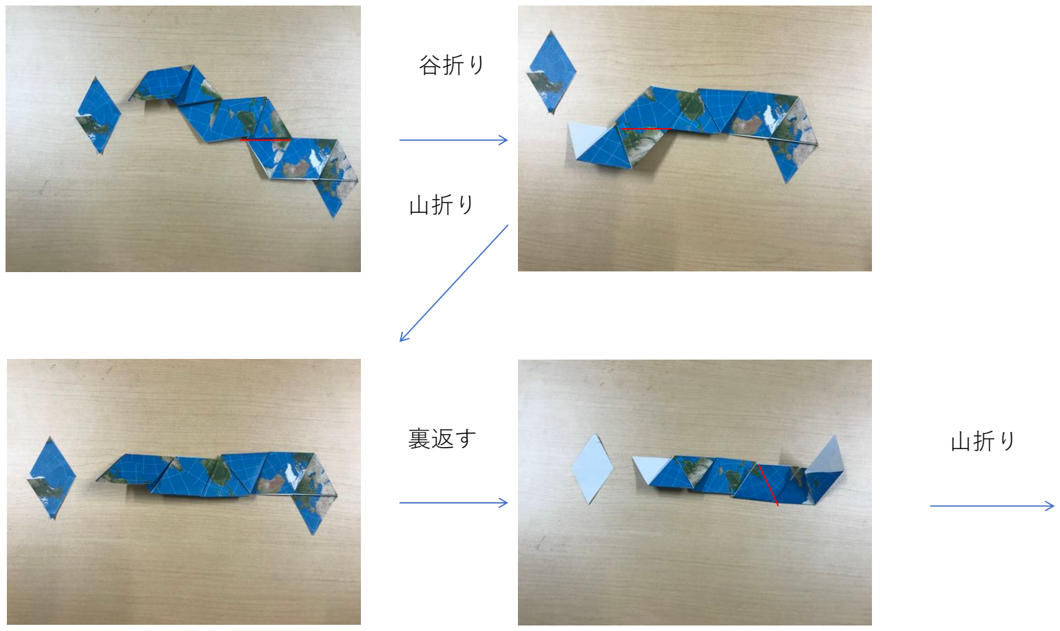
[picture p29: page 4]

⾕折り

⼭折り

裏返す | ⼭折り

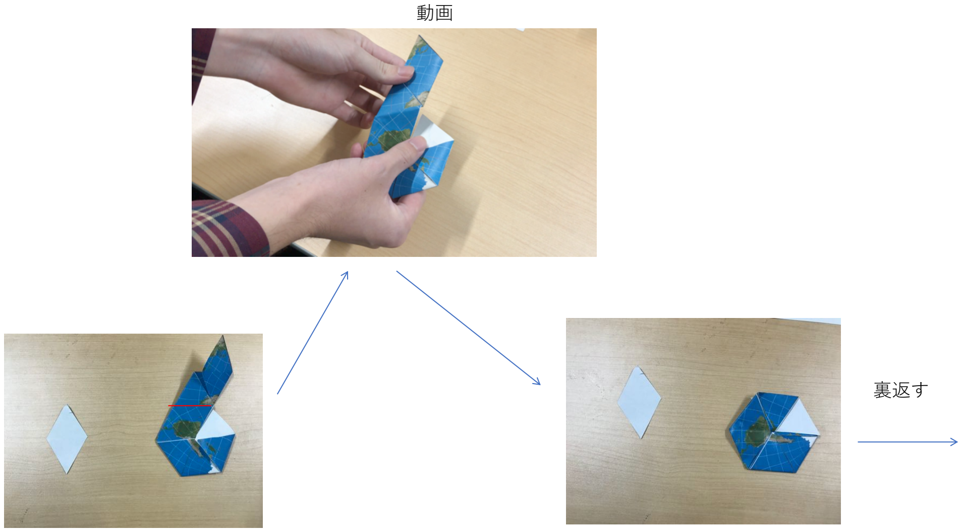
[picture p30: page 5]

動画

裏返す

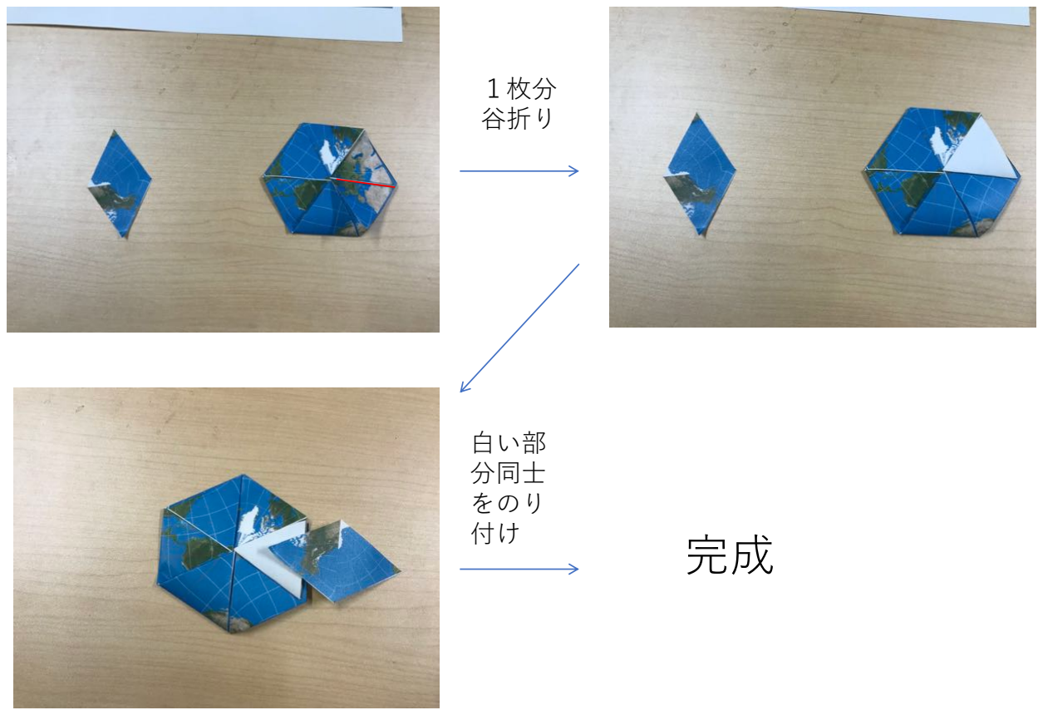
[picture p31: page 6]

１枚分
⾕折り

⽩い部
分同⼠
をのり
付け | 完成

## 出てくる６⾯

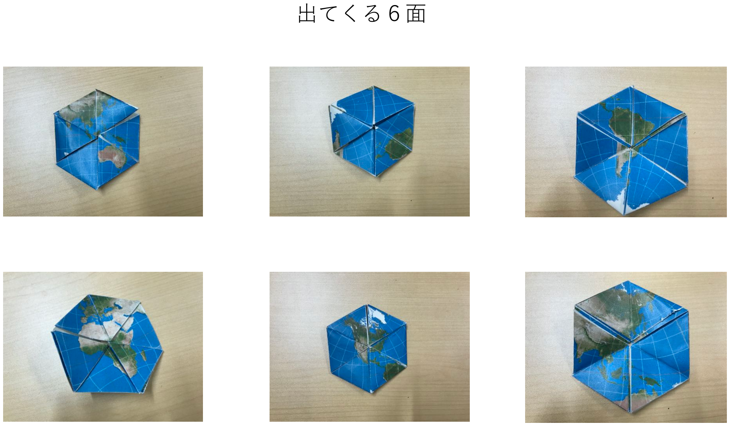
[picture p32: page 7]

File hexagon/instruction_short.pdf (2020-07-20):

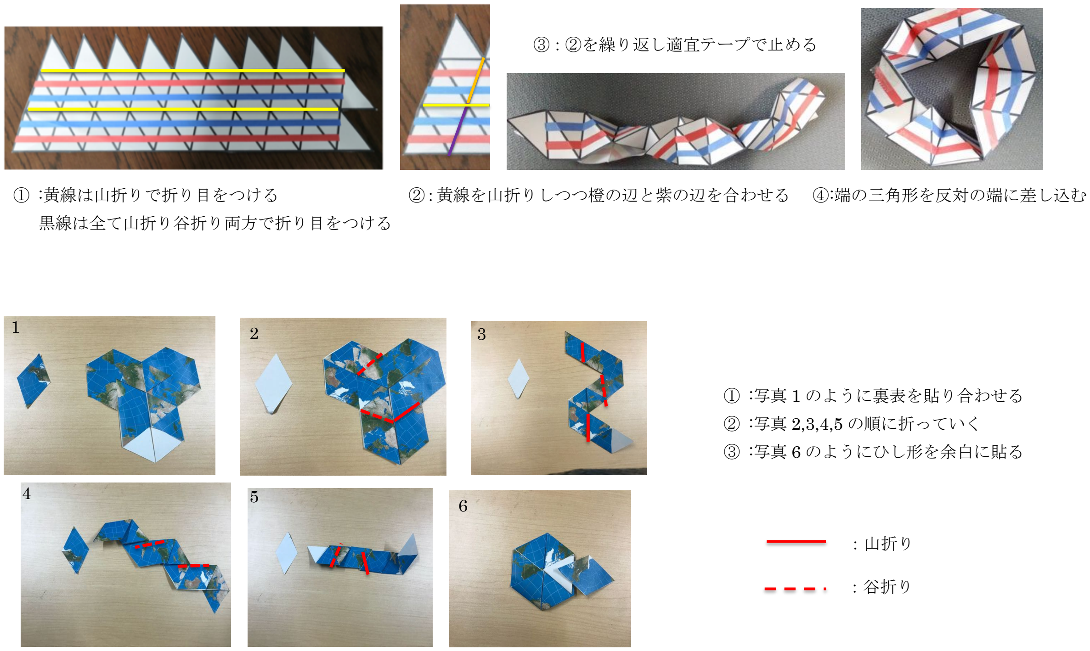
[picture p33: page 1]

① :黄線は山折りで折り目をつける | ②：黄線を山折りしつつ橙の辺と紫の辺を合わせる

黒線は全て山折り谷折り両方で折り目をつける

③：②を繰り返し適宜テープで止める

④:端の三角形を反対の端に差し込む

① :写真 1 のように裏表を貼り合わせる
② :写真 2,3,4,5 の順に折っていく
③ :写真 6 のようにひし形を余白に貼る
2 1 | 3
4 | 5 | 6

：山折り

：谷折り

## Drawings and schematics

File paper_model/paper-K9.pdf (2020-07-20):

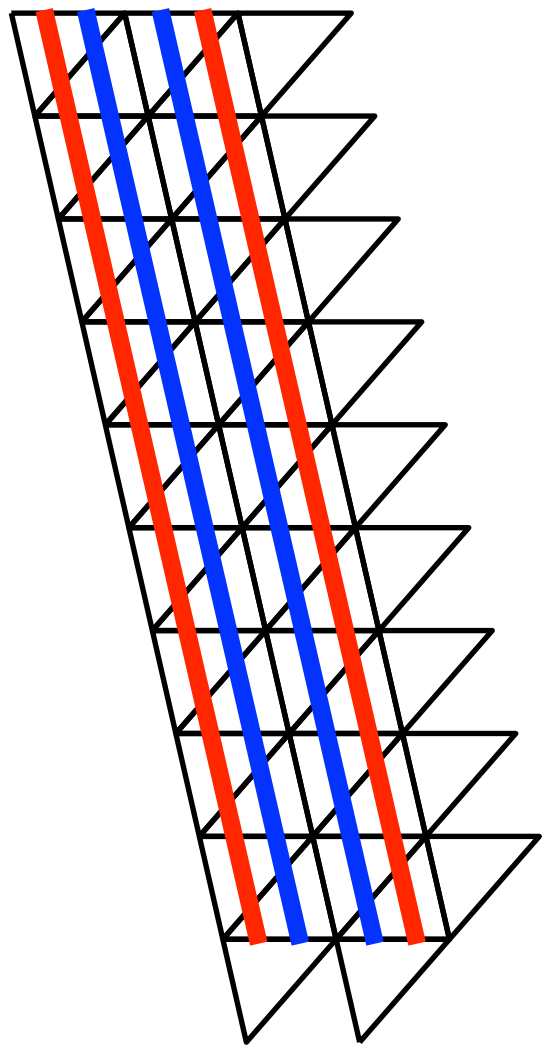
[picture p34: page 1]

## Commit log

2022-04-03 directory clean-up
    [Kaleidocycle_N7 Trefoil_all.stl, Kaleidocycle_N7 Trefoil_band.stl, Kaleidocycle_N7 Trefoil_hinge.stl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]
2025-12-03 add: mKdV motion
    [kaleidocycle_k8_nonoriented_bending.csv, kaleidocycle_k8_nonoriented_neg_mean_cos.csv]
2026-06-22 add: DoF analysis
    [kaleidocycle_k8_nonoriented_bending.csv, kaleidocycle_k8_nonoriented_neg_mean_cos.csv]
2026-08-12 add: flows
2026-09-02 add: web
    [kaleidocycle_k10_nonoriented_bending.csv, kaleidocycle_k10_oriented_bending.csv, kaleidocycle_k8_nonoriented_bending.csv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]
